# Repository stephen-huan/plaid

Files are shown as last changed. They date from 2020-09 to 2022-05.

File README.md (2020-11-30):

# Plaid

The Plaid is a 4x12 ortholinear keyboard made from through hole parts,
designed by [hsgw](https://github.com/hsgw/plaid).

My contributions include the design of an acrylic guard,
figuring out how to use an aluminium plate,
and a modified way to put the keyboard together.
I also include a way to flash the bootloader to the atmega328p with ArudinoISP.
USB-C variant of the keyboard TODO.

Three part video guide:
[[Part 1, Introduction]](https://www.youtube.com/watch?v=B0NsSwLFeV4)
[[Part 2, PCB and bootloader]](https://www.youtube.com/watch?v=xIaBSfZb_2U)
[[Part 3, Switches and finish]](https://www.youtube.com/watch?v=NNLFTtYiXNg)

[Build guide and BOM here](./doc)

## Pictures
Completed Plaid with an aluminium plate from SendCutSend
and an acrylic guard from Ponoko.
plaid full

Plaid without an acrylic guard or plate, and with an old fuse component.
Notice the alignment problems (right space is higher than left space,
"j" key (ま on the Hiragana keycaps) is also higher than its surroundings).
plaid

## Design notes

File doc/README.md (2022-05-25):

# Plaid // Through hole Documentation

## Assembly

Recommend reading the
[original Plaid documentation](https://github.com/hsgw/plaid/tree/master/doc)
first.

1. [Check the BOM to get the necessary parts](./md/BOM.md)
2. [Order a PCB](./md/pcb.md)
3. [Order an acrylic guard](./md/guard.md)
4. [Order a plate](./md/plate.md)
5. [Solder the PCB](https://github.com/hsgw/plaid/blob/master/doc/en/soldering.md)
6. [Flash the bootloader with ArduinoISP](./md/bootloader.md)
7. [Write QMK firmware](./md/firmware.md), you can use my personal
[keymap](https://github.com/stephen-huan/qmk_firmware/blob/vusb-nkro/keyboards/dm9records/plaid/keymaps/stephen-huan/keymap.c)
for inspiration
8. [Solder switches into the plate](./md/plate.md)
9. [Putting it all together](./md/complete.md)

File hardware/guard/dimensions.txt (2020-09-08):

228mm wide, 22mm tall
220mm horz. distance between screw hole centers
 14mm vert. distance between screw hole centers
m2 screw hole diameter: 2.2 close, 2.4 normal, 2.6 loose
5.657 at a 45 degree angle -> screw hole is 4mm from both edges
2.5mm radius rounding on the top left and right corners

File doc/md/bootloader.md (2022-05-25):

# Bootloader (with ArduinoISP)

Helpful links:
- [ArduinoISP](https://www.arduino.cc/en/tutorial/arduinoISP)
- [USBasploader](https://github.com/hsgw/USBaspLoader/blob/plaid/Makefile.inc)
(to get fuse data)
- [USBasploader](https://github.com/hsgw/USBaspLoader/commit/f7dad45af2a087508cf0997fa31f198fc984535f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)
(the actual bootloader data, save as `plaid.hex`)
- [QMK documentation](https://docs.qmk.fm/#/)
- [Plaid keyboard instructions](https://github.com/hsgw/plaid/blob/master/doc/en/bootloader.md)

## Steps

[[Video guide]](https://www.youtube.com/watch?v=pyH5Hi-ujLw)

### Setting up the Arduino IDE

1. Add the text from `bootloader/boards.txt` to the file at
`/Applications/Arduino.app/Contents/Java/hardware/arduino/avr/boards.txt`.
I'm going to refer to this path as just `avr` from now on.
Note that these changes revert whenever the Arduino IDE is updated.

2. Make a new folder called plaid in `avr/bootloaders`
and put the `bootloader/plaid.hex` file in that folder.

This is optional, but to remove the Arduino firmware
make an empty folder called plaid in `avr/cores`.
Also, make a folder called plaid in `avr/variants`,
and put an empty file called `pins_arduino.h` in it.

Alternatively, run the provided
[fish script](../../bootloader/plaid_arduino.fish)
(be sure to change the paths).

3. Load the ArudinoISP sketch onto the Arduino you're using
(File > Examples > 11.ArduinoISP > ArduinoISP).
Be sure to select the proper board for the Arudino you're using,
**not** the Plaid keyboard defined in steps 1-2.

### Wiring

Look for the 2x3 header pins on the Arduino labeled ICSP2
and the 2x3 header pins on the Plaid keyboard, labeled J2 and ISP
(left of the atmega328p and below the boot button).
Simply connect each pin of the Arduino to its corresponding pin on the Plaid
keyboard (MISO, +Vcc, SCK, MOSI, Reset, Gnd), with the exception of **reset**.
For some reason, the default ArduinoISP sketch uses pin 10 for reset.
So connect pin 10 on the Arduino to reset on the Plaid keyboard.

Only the Arduino needs to be plugged into your computer.

### Flashing

1. Set the board in the ArduinoIDE to the Plaid keyboard,
which was defined in steps 1-2 of setup.
(Tools > Board > Arduino AVR Boards > Plaid Keyboard)
2. Set the programmer to "Arudino as ISP" or "Arudino as ISP (ATmega32U4)" if
your Arduino uses an atmega32u4. (Tools > Programmer)
3. Press the "Burn Bootloader" button (Tools > Burn Bootloader)

If everything goes well, it should say "Avrdude done. Thank you."
with no error messages.

Follow the
[instructions](https://github.com/hsgw/plaid/blob/master/doc/en/bootloader.md)
in the original Plaid repository from here.

## EEPROM

If your keyboard has swapped keys for seemingly no reason,
especially if you're using the default Plaid keymap,
you may have written to the EEPROM, read-only memory for the microprocessor.
To reset the EEPROM, enter bootloader mode and run the following commands:
```bash
dfu-programmer atmega328p erase
dfu-programmer atmega328p flash --eeprom bootloader/eeprom_reset.hex
```

Or with `avrdude`:
```
avrdude -p m328p -c usbasp -U eeprom:w:bootloader/eeprom_reset.hex
```

`bootloader/eeprom_reset.hex` was taken from the
[QMK toolbox](https://raw.githubusercontent.com/qmk/qmk_toolbox/3d7c9b4c32f1bb7db49e4b0c2a65859fca20bd27/common/atmega32u4_eeprom_reset.hex).

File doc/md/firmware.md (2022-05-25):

# Firmware

Follow the getting started instructions of
[QMK](https://docs.qmk.fm/#/newbs_getting_started).

The steps to upload code to the keyboard are:
1. Enter bootloader mode
2. Flash the firmware

### Entering Bootloader Mode

1. Push and hold RESET switch
2. Push and hold BOOT switch
3. Release RESET switch
4. Release BOOT switch

### Flashing Firmware

After QMK has been setup, run
```bash
qmk flash -kb plaid -km stephen-huan
```
to write the firmware to the keyboard.

Note that after entering bootloader mode the keyboard will be unresponsive,
so you must run the command without using the keyboard's "enter" key. This
can be done with a different keyboard. QMK now automatically polls for a
new keyboard after running the flash command, so the flash command can be
ran _before_ entering bootloader mode, removing the need to run the command
_after_ the keyboard is unresponsive.

`qmk flash` will automatically compile the firmware. You
can also compile the firmware without flashing, with
```bash
qmk compile -kb <keyboard> -km <keymap>
```

### NKRO

N-key rollover (NKRO) refers to the capacity of a keyboard to register an
arbitrary number of keys pressed down. On a 6-key rollover (6KRO) keyboard,
for example, only 6 keys (excluding modifiers) can be detected at a time.
If more keys are pressed down, usually the first key to pressed down is
replaced by the new key (at least this is how
[QMK over V-USB works](https://github.com/qmk/qmk_firmware/blob/c3ff06c5345bbf781141c88ebbcca2bc575ead42/tmk_core/protocol/vusb/vusb.c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),
though the circular ring buffer data structure). Typically this is a pretty
useless feature, since the average person does not need to press down that
many keys. However, if one is trying to learn stenography with the open-source
[Plover](https://www.openstenoproject.org/plover/) software, a NKRO-supported
keyboard is
[almost required](https://github.com/openstenoproject/plover/wiki/Supported-Hardware#whats-nkro).
Typically "gamer" keyboards and high-end mechanical keyboards are the only
ones to support NKRO. The reason why it is a bit niche (and why so many myths
persist about NKRO) is that there _two_ important characteristics for a
keyboard to support NKRO: on the hardware side and on the software side.

On the hardware side, a good article is ["how to make a keyboard - the
matrix"]( http://blog.komar.be/how-to-make-a-keyboard-the-matrix/), which
discusses the details of scanning the key matrix. In summary, microcontollers
have a limited number of pins, which makes hooking each switch to a pin
impractical. Instead, the keys are arranged in a matrix, and pins are
assigned to columns and rows of this matrix. To get the value of a switch at
a particular row and a particular column, the appropriate pin for the row and
pin for the column are grounded to read the state. The problem is that if
multiple switches are pressed down, there can be interference since switches
are connected to each other through the matrix. The solution is to add a diode
to _each_ switch, which prevents this interference. This is why the plaid
[BOM](./BOM.md) requires 48 general purpose diodes, exactly one for each
switch. Keyboard manufactures are cheap however, and can't spare the few cents
per keyboard to add and solder diodes. Instead, there are various heuristics
and tricks, for example, to make sure commonly pressed keys together are
supported at the cost of rarer key combinations being impossible. This leads to
terms like "ghosting" (when a keycode is sent but its switch is not pressed,
leading to a "ghost" key), or "jamming" (when other switches being pressed
down prevents a new key from being registered). Again, these issues are caused
by the _hardware_ limitation of not using a diode per switch in a key matrix,
and no amount of clever software programming can avoid these issues in general.

On the software side, there are also a lot of myths. A good
article to read is ["Myths about USB NKRO and how USB HID
works"](https://www.devever.net/~hl/usbnkro). The gist is that there are
two different modes: a simplified mode meant for BIOS (on bootup), which
will be referred to "boot mode", and a more complex mode taking advantage
of the USB Human Interface Device (HID) specification. In BIOS mode, the
keyboard sends 8 modifiers (as a single byte, each modifier is a bit), as
well as the last 6 keys. These keys are encoded as _keycodes_, so if there
are 256 possible keys, each key is assigned a number, so each key takes
a byte to encode. This is where the common 6KRO limitation comes from.
Instead, if we were trying to support NKRO, it would be more efficient to
encode keys as a bit mask, that is, a bit for each key indicating whether
it was pressed down or not. This requires the use of the more complicated
but more general USB HID interface. Note that clearly USB is able to support
NKRO, so there is no basis for the myth that only PS/2 connectors are
able to support NKRO because of the limitations of the USB protocol.

In summary, for a keyboard to support NKRO:
- On the hardware side, there must be a diode per key switch. This
  is true for most hobbyist mechanical keyboards, including the plaid.
- On the software side, the firmware must support the more
  general USB HID interface instead of just the BIOS boot mode.

We now come to the specific case for the plaid keyboard. The plaid keyboard
does have a diode per switch, so the hardware on that front is fine. However,
it uses the atmega328p microcontroller, which does not have hardware
USB support. Instead, USB is done through the pins through firmware, in
particular, with [V-USB](https://www.obdev.at/products/vusb/index.html).
This means that the number of endpoints is limited as well as the data
transfer is limited to 8 byte packets. On the software side, QMK supports
NKRO for most keyboards. However, because of these complexities with
V-USB, [NKRO is disabled](https://github.com/qmk/qmk_firmware/pull/9054).
Again, this is not because it is impossible, it is disabled simply
because nobody has wrote code to support NKRO over V-USB. Until this
[pull request](https://github.com/qmk/qmk_firmware/pull/12010),
which unfortunately has not been merged. I maintain a [QMK
fork](https://github.com/stephen-huan/qmk_firmware/tree/vusb-nkro) with
the patch applied.

QMK also supports the [stenography](https://docs.qmk.fm/#/feature_stenography)
protocol, that is, it is able to use the TX Bolt or
GeminiPR protocols. However, due to V-USB [endpoint
limitations](https://github.com/qmk/qmk_firmware/issues/13834) it is
[unlikely to be supported](https://github.com/qmk/qmk_firmware/pull/12010#issuecomment-1088451512).
It remains to be seen if someone will write code for virtser over V-USB.

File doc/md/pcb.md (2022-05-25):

# PCB

Upload `gerber_plaid.zip` and `gerber_plaid_bottom.zip`
to [JLCPCB](https://jlcpcb.com/) (by far the cheapest PCB printing service,
even with the minimum order quantity of 5).

Gerber files were generated according to the instructions
[here](https://support.jlcpcb.com/article/44-how-to-export-kicad-pcb-to-gerber-files).

Go into the `pcb/gerber` folder and generate `gerber_plaid.zip` with:
```bash
zip -r gerber_plaid.zip plaid/
```
and similarity, for `gerber_plaid_bottom.zip`:
```bash
zip -r gerber_plaid_bottom.zip plaid_bottom/
```

Use these settings when ordering:
- PCB thickness: 1.6mm
- Surface finish: HASL (with lead) [can change according to preference]
- Remove order number
- PCB color: white looks nice

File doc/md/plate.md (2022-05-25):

# Plate

Upload `hardware/plate/GRID_planck_hipro.dxf`
to [SendCutSend](https://sendcutsend.com/).
Recommended material is 5052 Aluminium, 1.6mm thick.

DXF file taken from [LaserBoost](https://www.laserboost.com/plates-planck),
the Planck Grid Hi-Pro plate. The Planck is a different PCB, but the dimensions
and screw hole placement are the same.

What are the advantages of using a plate?

1. Switches are aligned, so everything is nice and straight.
2. Flex is noticeably reduced (without a plate, pressing down will bend
the PCB. With a plate, the plate absorbs most of the force).
3. Dust and other particulate accumulates on the plate instead of the PCB.

## Soldering switches
Press switches into the plate until it clicks.
Make sure alignment is correct.
One switch at the bottom row and 7 switches from the left will be facing in the
opposite direction as the others, because of the PCB design -
this allows the PCB to support both the grid and MIT layout.

Once all the switches are pressed into the plate, proceed to solder as usual.
I recommend soldering the four switches at the corners of the plate first
to guarantee that the plate is flat and aligned with the PCB.

[[Video guide]](https://www.youtube.com/watch?v=NNLFTtYiXNg)

completed
Plate fits onto the Plaid PCB although it's a Planck plate!
Soldered switches, note that the hole on the switch on the bottom row
and 7 from the left has its hole pointing upwards compared to the other switches
pointing downwards, as stated above.

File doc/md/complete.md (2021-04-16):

# Putting it All Together

There are two main ways to attach the top PCB to the bottom PCB.
One is the way described in the Plaid
[build guide](https://github.com/hsgw/plaid/blob/master/doc/en/complete.md),
which takes advantage of the fact that a M2 nut is 1.6mm high, and so is the
PCB. Thus, 2 PCB layers and 3 nuts are exactly 5*1.6mm = 8mm high.
So a 8mm M2 screw inserted from the top of the top PCB, two nuts between it and
the bottom PCB, and then fastened with the final nut will exactly fit.
However, in my experience, the nuts fall out.

A different way to attach the two PCBs together is with a 3mm spacer.
2*1.6mm + 3mm = 6.2mm, so the screws have to be less than 3.1mm long.
First, insert one 3mm screw from the top of the top PCB, and screw the spacer
onto it. Then, screw another 3mm screw from the bottom of the bottom PCB into
the existing spacer and it will fasten.

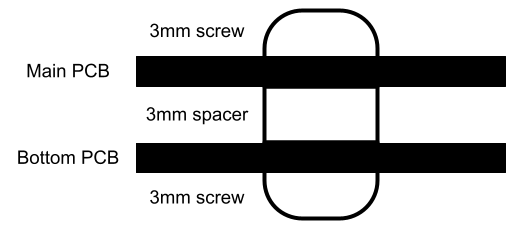
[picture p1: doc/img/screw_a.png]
screw_a


To install the acrylic guard, use an 8mm screw instead of a 3mm screw going
from the bottom PCB to the top PCB, and simply screw the 10mm spacers onto
this screw. From there, place the acrylic guard over the four spacers, making
sure the rounded corners are at the top left and right. Screw 4 8mm screws
downwards, securing the acrylic guard. I recommend half-screwing each screw into
its spacer first, to make sure all screws can go in, and then fully screwing
all four screws after they are all in place.

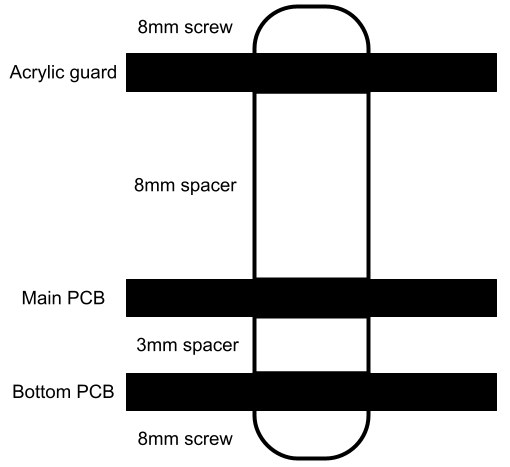
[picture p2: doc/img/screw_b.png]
screw_b


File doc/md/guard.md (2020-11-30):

# Acrylic Guard

Upload `hardware/guard/guard.dxf` to [Ponoko](https://www.ponoko.com/).
Recommended material is Clear Impact Modified Acrylic, 2.0mm thick.

Guard prototype designed by [Udbhav Muthakana](https://github.com/udbhav1),
polished by [me](https://github.com/stephen-huan).

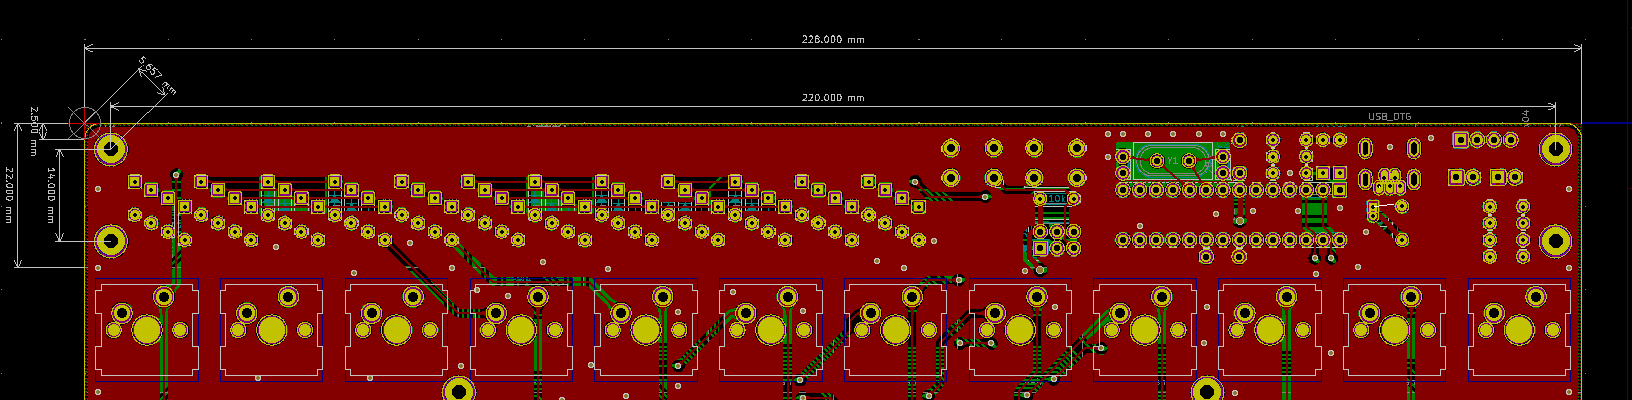
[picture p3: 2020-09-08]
hardware/guard/diagram.png

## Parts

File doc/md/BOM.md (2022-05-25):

# BOM

## Included in Plaid kit
| | Ref | Qty | Value | Description | Vendor |
|---|---|-----|---|---|---|
| 22pF | C1, C2 | 2 | 22p | Multi layer ceramic capacitor (2.5mm pitch) | [Mouser](https://www.mouser.com/ProductDetail/81-RCE5C2A220J0A2H3B) |
| 4.7uF  | C3 | 1 | 4.7u | Electrolytic capacitor (1.5mm pitch) | [Mouser](https://www.mouser.com/ProductDetail/647-UMT1V4R7MDD) |
| 100nF  | C4, C5 | 2 | 100n | Multi layer ceramic capacitor (5mm pitch) | [Mouser](https://www.mouser.com/ProductDetail/81-RDER71H104K0M1H3A) |
| 1N4148 | D1-48 | 48  | 1N4148 | General-purpose diode (DO-35) | [Mouser](https://www.mouser.com/ProductDetail/512-1N4148TR) |
| 3.6V | D49, D50 | 2 | 3.6V | 3.6V zener diode (DO-35) | [Mouser](https://www.mouser.com/ProductDetail/78-TZX3V6A) |
| fuse | F1 | 1 | 100mA | Resettable fuse (5mm pitch) | [Mouser](https://www.mouser.com/ProductDetail/504-PTR060V0010-BK) |
| | | | | Alternative fuse | [Mouser](https://www.mouser.com/ProductDetail/652-CMF-RL25-0) |
| USB | J1 | 1 | USB MINI-B  | USB miniB connector | [Mouser](https://www.mouser.com/ProductDetail/538-54819-0519) |
| 2x3 | J2 | 1 | 02x03 | AVR ISP pin header | [Mouser](https://www.mouser.com/ProductDetail/649-68602-406HLF) |
| LED | LED1,2 | 2 | RED, GREEN  | 3mm LED | [Mouser](https://www.mouser.com/ProductDetail/859-LTL-4222) |
| | | | | Green | [Mouser](https://www.mouser.com/ProductDetail/859-LTL-4232) |
| 1.5k | R1, R7, R8  | 3 | 1.5k | 1/6W resistor | [Mouser](https://www.mouser.com/ProductDetail/603-MFR-12FTF52-1K5)  |
| 75R | R2, R3 | 2 | 75R | 1/6W resistor | [Mouser](https://www.mouser.com/ProductDetail/603-CFR-12JR-52-75R)  |
| 10k | R4 | 1 | 10k | 1/6W resistor | [Mouser](https://www.mouser.com/ProductDetail/603-MFR-12FRF5210K) |
| | SW50, SW51  | 2 | RESET, BOOT | 6mm tactile switch | [Mouser](https://www.mouser.com/ProductDetail/642-MJTP1230A) |
| | U1 | 1 | ATMEGA328P  | | [Mouser](https://www.mouser.com/ProductDetail/556-ATMEGA328P-PU) |
| | IC Socket | 1 | 28pin | 28pin IC Socket | [Mouser](https://www.mouser.com/ProductDetail/571-1-2199298-9) |
| | Y1 | 1 | 16MHz | | [Mouser](https://www.mouser.com/ProductDetail/449-LFXTAL058383BULK) |
| | PCB | 1 | MAIN PCB | | [JLCPCB](https://jlcpcb.com/) |
| | PCB | 1 | BOTTOM PCB  | | [Guide](http://www.40percent.club/2017/03/ordering-pcb.html) |
| | Rubber Feet | 4 | | | [Amazon](https://www.amazon.com/dp/B01N922DLO) |

## Mounting strategies

Original Plaid strategy (if not using acrylic guard, don't need the 4 spacers):
| Ref | Qty | Value | Vendor |
|---|-----|---|---|
| Screw  | 14  | M2 8mm | [Amazon](https://www.amazon.com/dp/B000NHXO1M) |
| Nut | 26  | M2 0.4mm | [Amazon](https://www.amazon.com/dp/B07H3VBRL6) |
| Spacer | 4 | M2  10mm | [Amazon](https://www.amazon.com/dp/B0854BNKZP) |

Alternative strategy (if not using acrylic guard, replace
8mm screws with 3mm screws, and don't need 10mm spacers):
| Ref | Qty | Value | Vendor |
|---|-----|---|---|
| Screw  | 12  | M2  3mm | [Amazon](https://www.amazon.com/dp/B00W96Z5RQ) |
| Spacer | 10  | M2  3mm | [Amazon](https://www.amazon.com/dp/B07H3SND59) |
| Screw  | 8 | M2  8mm | [Amazon](https://www.amazon.com/dp/B000NHXO1M) |
| Spacer | 4 | M2 10mm | [Amazon](https://www.amazon.com/dp/B0854BNKZP) |

## Not included
- 48 PCB mount switches
    - I recommend Kailh box crystal jades from [NovelKeys](https://novelkeys.xyz/products/box-crystal-switches)
    - If using linears, lube with [Krytox 205g0](https://novelkeys.xyz/products/lubricants),
[Spotter 5/0 paintbrush](https://www.amazon.com/dp/B0043GCYTW),
[tweezers](https://www.amazon.com/dp/B00FZPEWI6)
    - [Lube guide](https://topclack.com/textclack/2018/9/17/the-switch-lab-a-living-switch-modification-guide),
[video](https://www.youtube.com/watch?v=qSgPKPoFo2k),
[choosing lube](https://switchandclick.com/2020/01/22/what-lube-to-use-for-mechanical-keyboard-switches/)
- [USB miniB cable](https://www.amazon.com/dp/B00NH13S44)

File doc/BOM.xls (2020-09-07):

PLAID
Mouser # | Mfr. # | Manufacturer | Customer # | Description | RoHS | Lifecycle | Order Qty. | Price (USD) | Ext.: (USD)
81-RCE5C2A220J0A2H3B | RCE5C2A220J0A2H03B | Murata |  | Multilayer Ceramic Capacitors MLCC - Leaded 22pF 100volts C0G LS=2.5mm +/-5% | RoHS Compliant |  | 2 | $0.48 | $0.96
512-1N4148TR | 1N4148TR | ON Semiconductor |  | Diodes - General Purpose, Power, Switching Hi Conductance Fast | RoHS Compliant |  | 48 | $0.053 | $2.54
78-TZX3V6A | TZX3V6A-TR | Vishay |  | Zener Diodes 3.6 Volt 0.5W 10% | RoHS Compliant By Exemption |  | 2 | $0.20 | $0.40
538-54819-0519 | 54819-0519 | Molex |  | USB Connectors USB Mini-B Recept On-The-Go Rt.Angle | RoHS Compliant |  | 1 | $1.71 | $1.71
859-LTL-4222 | LTL-4222 | Lite-On |  | Standard LEDs - Through Hole Red Transparent | RoHS Compliant |  | 1 | $0.12 | $0.12
859-LTL-4232 | LTL-4232 | Lite-On |  | Standard LEDs - Through Hole Green Transparent | RoHS Compliant |  | 1 | $0.12 | $0.12
603-MFR-12FTF52-1K5 | MFR-12FTF52-1K5 | Yageo |  | Metal Film Resistors - Through Hole 1.5K OHM 1/6W 1% | RoHS Compliant |  | 3 | $0.14 | $0.42
603-CFR-12JR-52-75R | CFR-12JR-52-75R | Yageo |  | Carbon Film Resistors - Through Hole 75ohm 5% 1/6W Carbon Film | RoHS Compliant |  | 2 | $0.10 | $0.20
603-MFR-12FRF5210K | MFR-12FRF52-10K | Yageo |  | Metal Film Resistors - Through Hole 10K OHM 1% 100PPM | RoHS Compliant |  | 1 | $0.10 | $0.10
642-MJTP1230A | MJTP1230A | Apem |  | Tactile Switches 6mm square tact | RoHS Compliant |  | 2 | $0.20 | $0.40
556-ATMEGA328P-PU | ATMEGA328P-PU | Microchip |  | 8-bit Microcontrollers - MCU 32KB In-system Flash 20MHz 1.8V-5.5V | RoHS Compliant |  | 1 | $2.08 | $2.08
571-1-2199298-9 | 1-2199298-9 | TE Connectivity |  | IC & Component Sockets 28P DIP SKT 300 CL LADDER | RoHS Compliant |  | 1 | $0.46 | $0.46
449-LFXTAL058383BULK | LFXTAL058383Bulk | IQD Frequency Products |  | Crystals 16MHz 20pF -40C 85C | RoHS Compliant |  | 1 | $0.52 | $0.52
81-RDER71H104K0M1H3A | RDER71H104K0M1H03A | Murata |  | Multilayer Ceramic Capacitors MLCC - Leaded 0.1uF 50volts X7R 10% | RoHS Compliant |  | 2 | $0.31 | $0.62
647-UMT1V4R7MDD | UMT1V4R7MDD | Nichicon |  | Aluminum Electrolytic Capacitors - Radial Leaded 35volts 4.7uF 4x5 20% 1.5LS | RoHS Compliant |  | 1 | $0.20 | $0.20
649-68602-406HLF | 68602-406HLF | FCI / Amphenol |  | Headers & Wire Housings 6P DR VRT UNSHRD HDR TIN OVER NICKEL | RoHS Compliant |  | 1 | $0.24 | $0.24
504-PTR060V0010-BK | PTR060V0010-BK | Eaton |  | Resettable Fuses - PPTC 60V 0.1A Radial | RoHS Compliant |  | 1 | $0.44 | $0.44

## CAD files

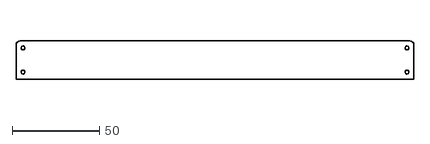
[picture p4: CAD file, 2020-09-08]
hardware/guard/guard.dxf
228.0 x 22.0

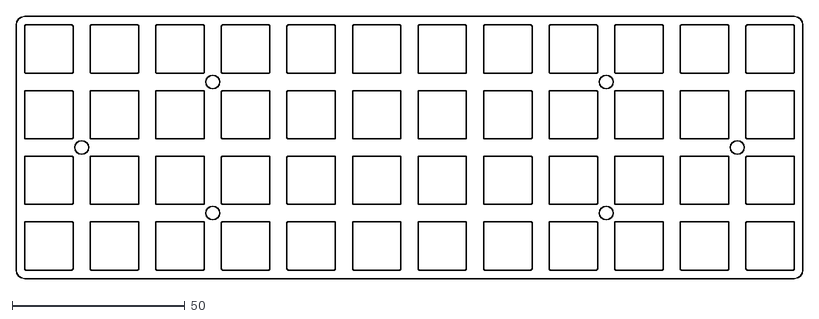
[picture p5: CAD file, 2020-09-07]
hardware/plate/GRID_planck_hipro.dxf
228.0 x 76.0

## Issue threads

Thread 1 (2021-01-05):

USB C Plaid

stephen-huan, 2021-01-05:
Switch from Micro-USB to USB-C by redesigning PCB.
Note: this has already been [done](https://github.com/hsgw/plaid/pull/27), but they put the two resistors to the right of the connector, moving the LEDs. There is a nice, empty, space below the reset button and to the left of the 2x3 header. Putting the 2 5.1 kohm resistors there has also already been [done](https://keycapsss.com/diy-kits/90/plaid-gold-keyboard-kit-usb-c-mx/choc?c=17) but not in an open-source manner (as far as I'm aware).

- Copy [romeo](https://github.com/coseyfannitutti/romeo) (very similar, atmega382pu, usb c)
- Need to add 2 5.1 kohm resistors
- [PCB design guide](https://wiki.ai03.com/books/pcb-design/page/usb-type-c)

piit79, 2021-03-03:
Hey, thanks for mentioning my pull request. This was actually my very first attempt at a PCB modification in KiCad, and it shows :) I didn't dare change much, and I still managed to botch the schematics on the first proto :) I'll try to improve the layout of the PCB soon according to your comments.

stephen-huan, 2021-03-03:
Oh haha, these were just notes to myself if I ever got around to re-designing the PCB. No worries, I don't have any electronics experience so it was helpful to see what others had done. I did not know GitHub linked these...

Sorry for the trouble, I would have worded the message nicer if I knew someone other than myself would have read it :p

piit79, 2021-03-04:
Hey, don't worry! I didn't take any offence :) As I said, that was my very first foray into KiCad, so I'm sure it's less than optimal to say the least. It was the best I could do back then, but I've practiced quite a bit since, so I should probably revisit :)

Closed 2024-05-03.

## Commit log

2020-09-08 add guard design
    [guard.dxf]
2020-09-14 plate pictures
2020-09-18 add picture of final Plaid with plate
2020-09-29 add image of ponoko plate
2020-11-30 organize files, add gerber files
    [GRID_planck_hipro.dxf, guard.dxf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]
2020-11-30 reorganize README
    [BOM.xls]
2021-04-16 be more precise about alternative mounting in BOM
2021-04-16 better screw diagrams
